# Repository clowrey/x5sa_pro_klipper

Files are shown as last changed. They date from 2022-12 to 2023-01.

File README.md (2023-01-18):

# x5sa_pro_klipper
Edit: the printer.cfg firmware in the "archive" folder is for the original Tronxy board, new one is for the BTT Octopus Pro I am currently using. 
This firmware is only for the V6-191121 motherboard - based on instructions here: https://tronxy.fandom.com/wiki/Installing_Klipper

To install firmware place the "update" folder on an SD card and power on the printer, it should update and the screen will stop working. It now will work with Klipper!

Install Mainsail OS https://docs.mainsail.xyz/setup/ on your raspberry pi or other SBC

Use basic Klipper guide's to help you get familiar with how Klipper works... 

Copy the "printer.cfg" file contents into Mainsail OS klipper config either through the web interface or through SSH, SFTP etc.. 

I am currently using Bambulabs Studio fork Softfever with the Tronxy with good results, you can import the config for that from the folder in this repository.
https://github.com/SoftFever/BambuStudio-SoftFever

Old:
Install super slicer https://github.com/supermerill/SuperSlicer/releases

File - Import - Import Config Bundle - and use the bundle in this repository

Video of my nozzle + linear rail + lower endstop contact bed leveling setup:
https://youtu.be/urmSgkl6vnU

Video of it printing before attaching accelerometer and motion shaper:
https://youtu.be/9MZbLJ6z8Nc

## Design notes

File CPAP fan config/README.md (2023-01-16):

**Klipper config for CPAP directly to BTT Octopus pro or Mellow Super 8 - or really any MB with similar shematic**

It should work on any of the 3 pin headers because they all use the same basic output schematic. 

The stock 3 pin 2.54mm pitch connector that goes from CPAP driver PCB to the variable resistor is actually the same 3 pin connector used on these MB! So you just have to move the pins around with small flat head screwdriver.. 

*Mellow Super 8 section below these pictures*

```yaml
[fan] #        CPAP print Cooling Fan\
pin: PG15 # for ocotopus pro Endstop 7 header
max_power: 1 # adjust below 1 if you would like the max speed to be slower
off_below: 0.2 # minimum speed where the fan starts spinning - on octopus pro this is correct - will be lower maybe 0 on mellow Super 8 because of different GPIO pullup and protection resistors
cycle_time: .0005 # = 2khz - CPAP fan driver recommended range is 2-50khz
```

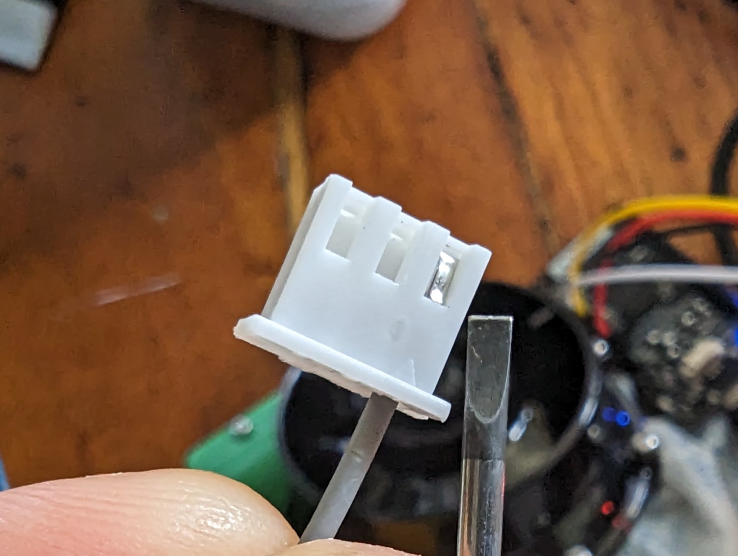
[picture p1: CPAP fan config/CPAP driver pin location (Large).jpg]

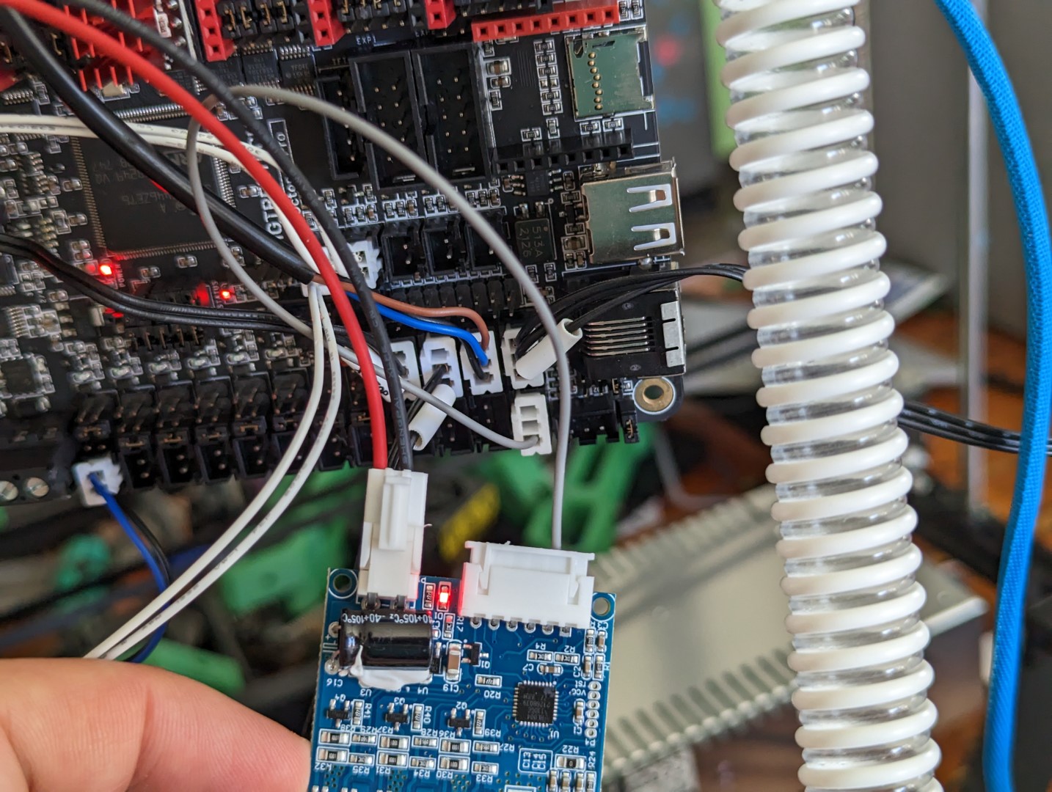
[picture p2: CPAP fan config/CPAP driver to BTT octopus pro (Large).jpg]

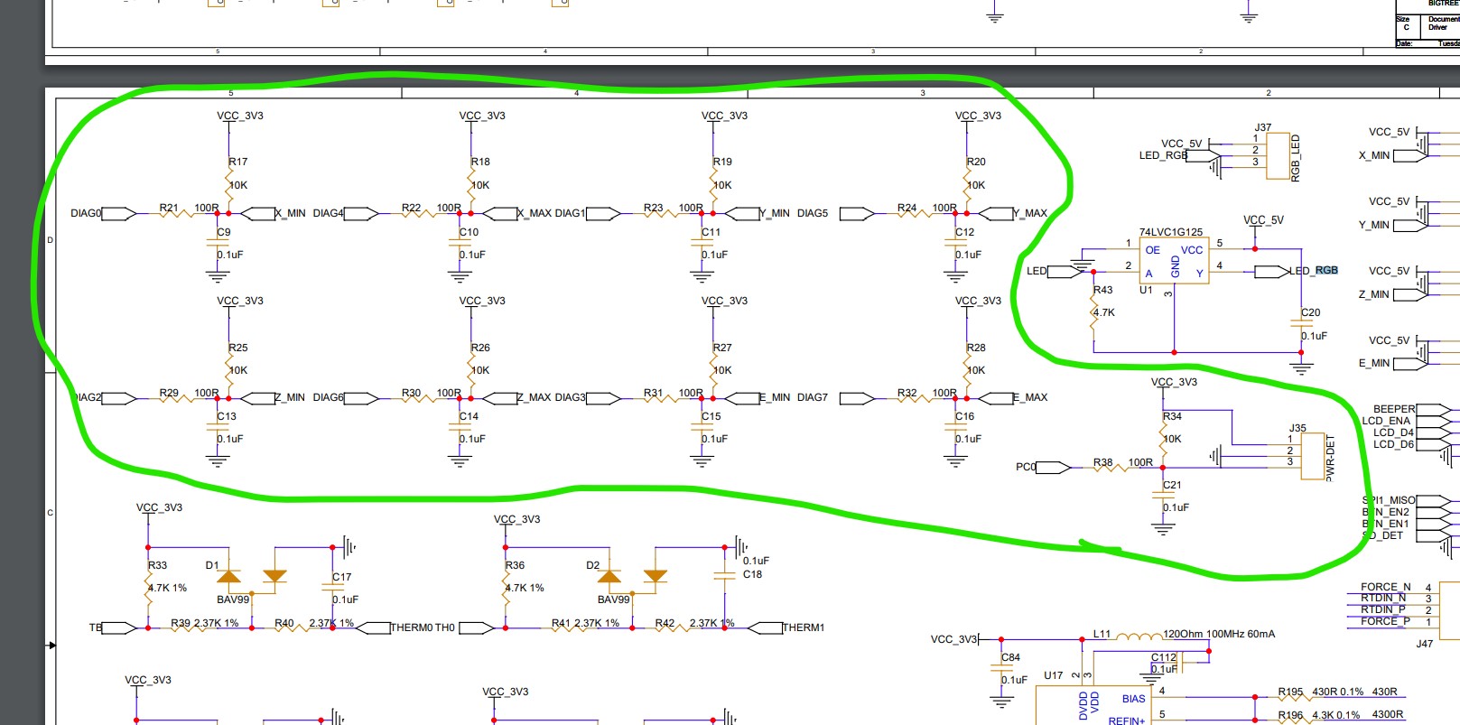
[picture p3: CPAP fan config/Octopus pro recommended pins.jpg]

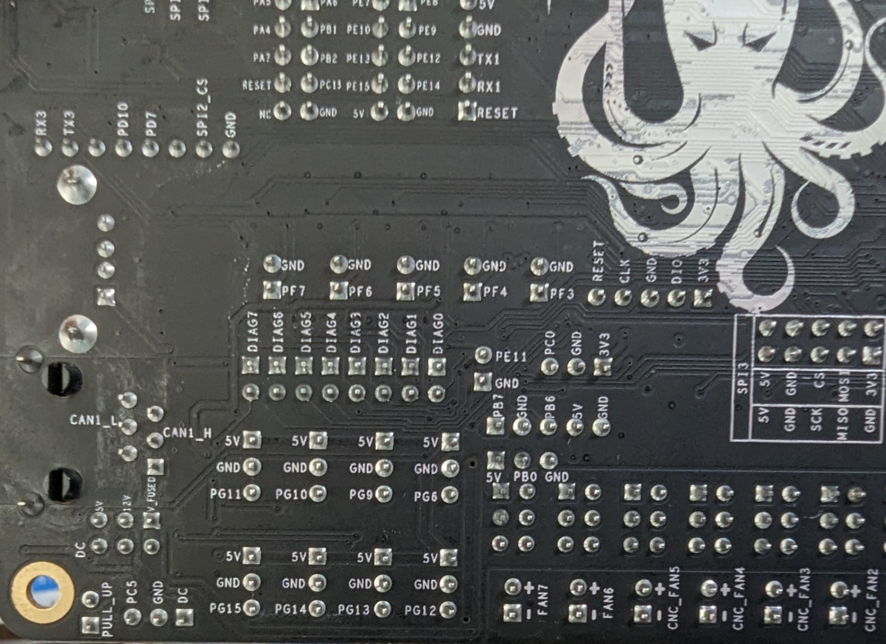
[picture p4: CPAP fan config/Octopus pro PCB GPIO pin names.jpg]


**Mellow Super 8 CPAP Config**

For the Mellow Super 8 the output schematic is quite different - with a 1k series resistor on almost all of the output pins, this in combination with the 10k pullup allows for the lowest voltage to be 0.3v - which is still below the turn on voltage of the CPAP fan driver I believe. 

The green circled HV in pin is the best one to use as it has no pullup. The other ones in yellow have 10k pullups so would be the second choice and should still work fine. 

here is a klipper example using the HV IN header:

```yaml
[fan] #        CPAP print Cooling Fan\
pin: PF3 # for mellow super 8 HI IN header
max_power: 1 # adjust below 1 if you would like the max speed to be slower
off_below: 0.2 # minimum speed where the fan starts spinning - on octopus pro this is correct - 
# will be lower maybe 0 on mellow Super 8 on pins with 10k pullup because of different GPIO pullup and protection resistors
# on HVin pin PF3 it will probably be 0.2 because of no pullup
cycle_time: .0005 # = 2khz - CPAP fan driver recommended range is 2-50khz
```

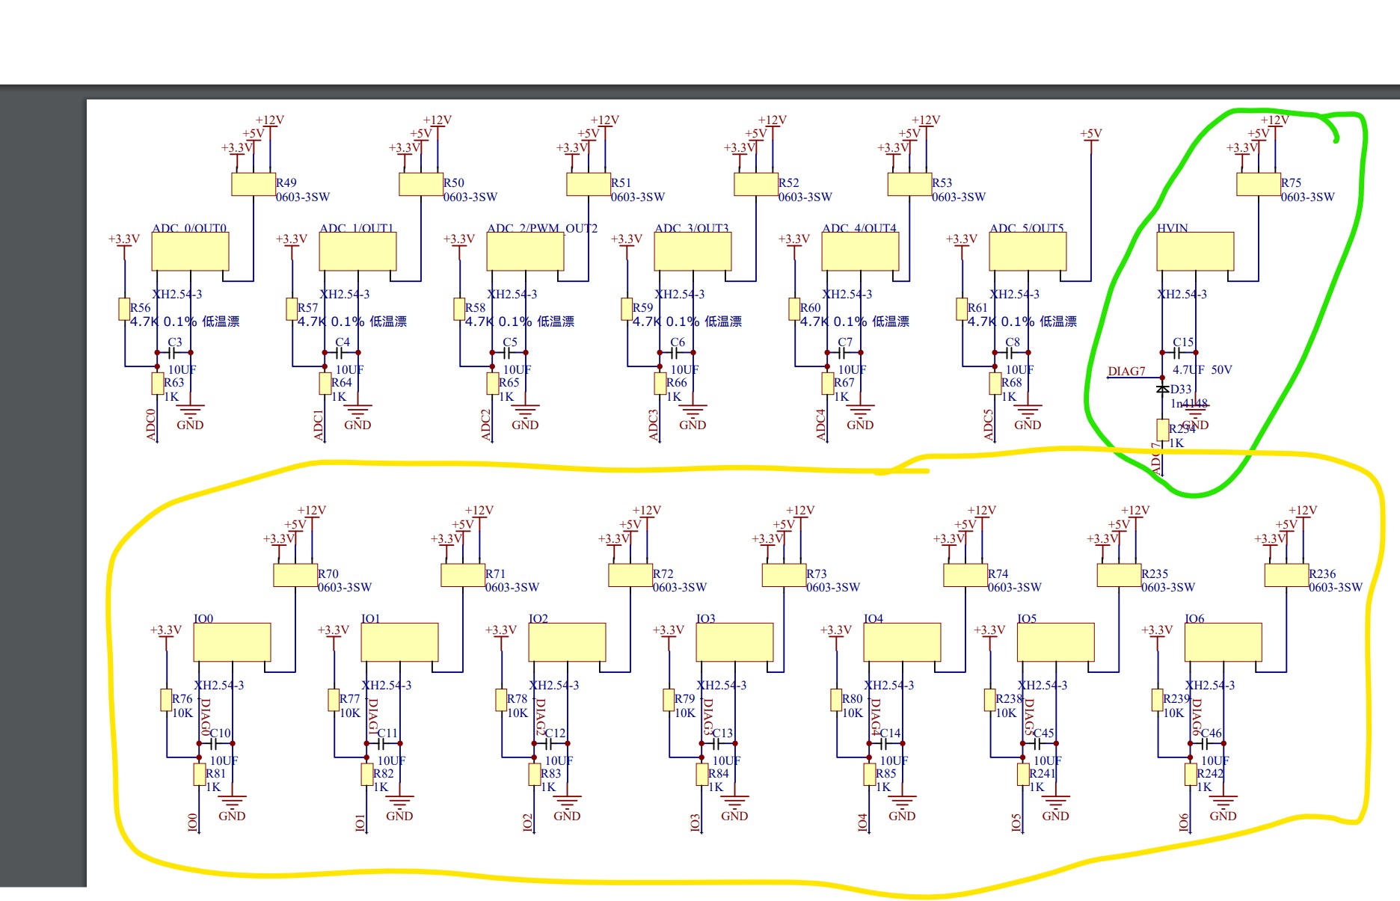
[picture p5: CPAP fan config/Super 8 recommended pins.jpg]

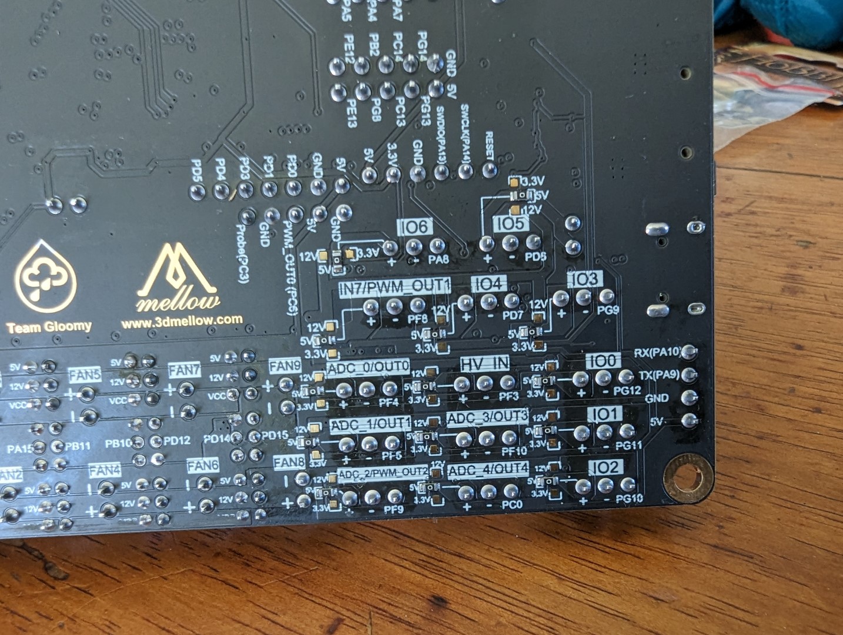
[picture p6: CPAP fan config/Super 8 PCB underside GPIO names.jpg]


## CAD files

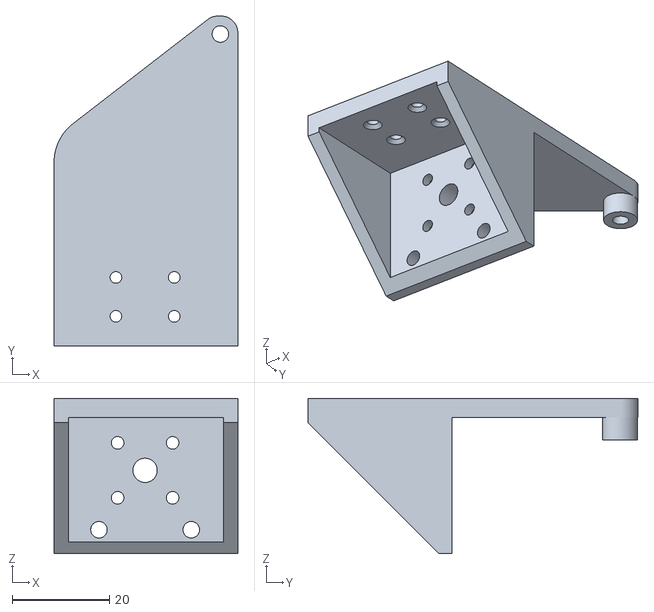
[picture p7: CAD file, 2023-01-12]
tronxy mount linear rail.stl
37.8 x 67.9 x 32.0

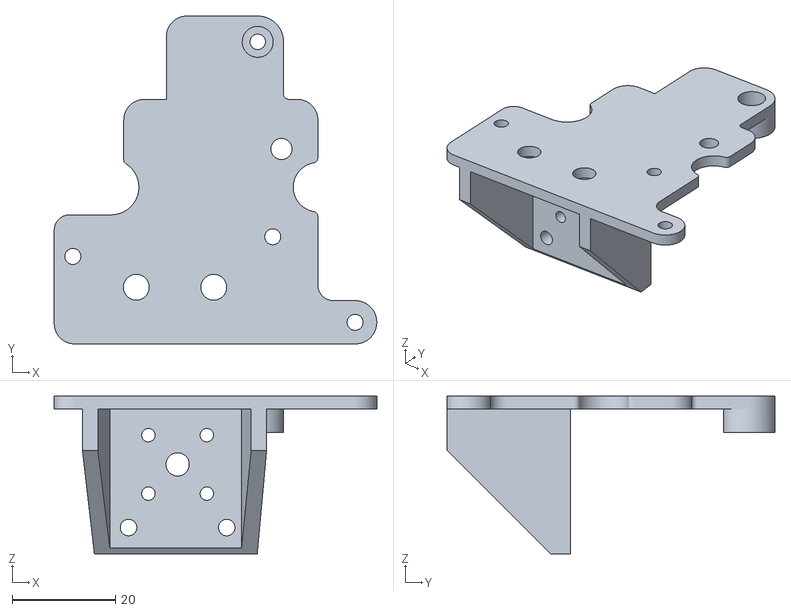
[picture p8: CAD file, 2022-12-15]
extruder_tronxy.obj
62.4 x 63.5 x 30.5

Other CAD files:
tronxy mount linear rail.obj

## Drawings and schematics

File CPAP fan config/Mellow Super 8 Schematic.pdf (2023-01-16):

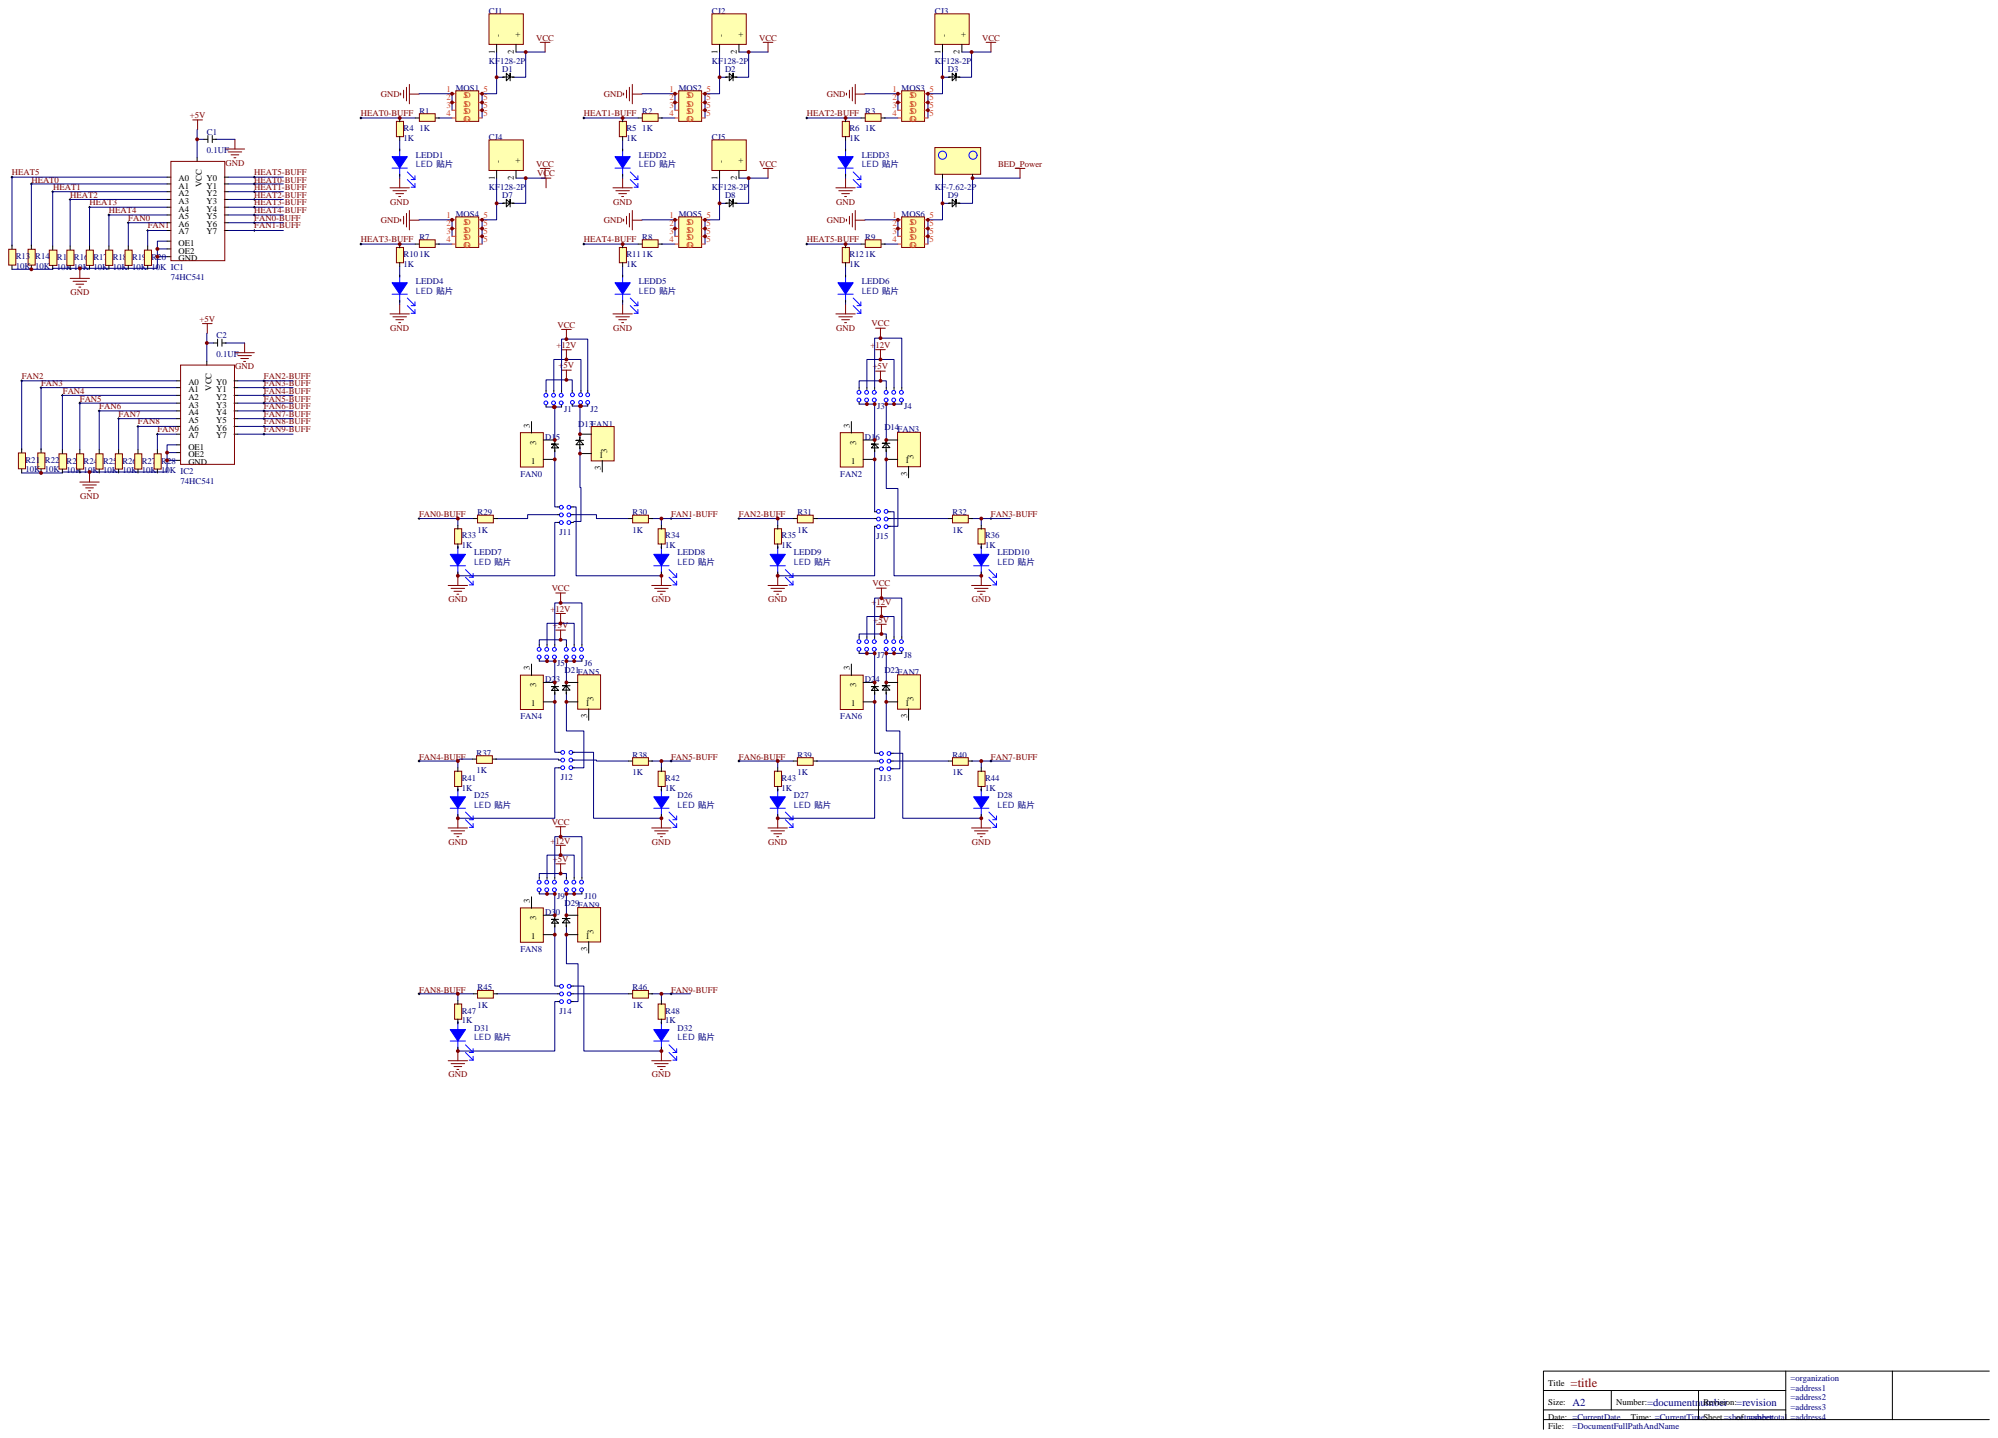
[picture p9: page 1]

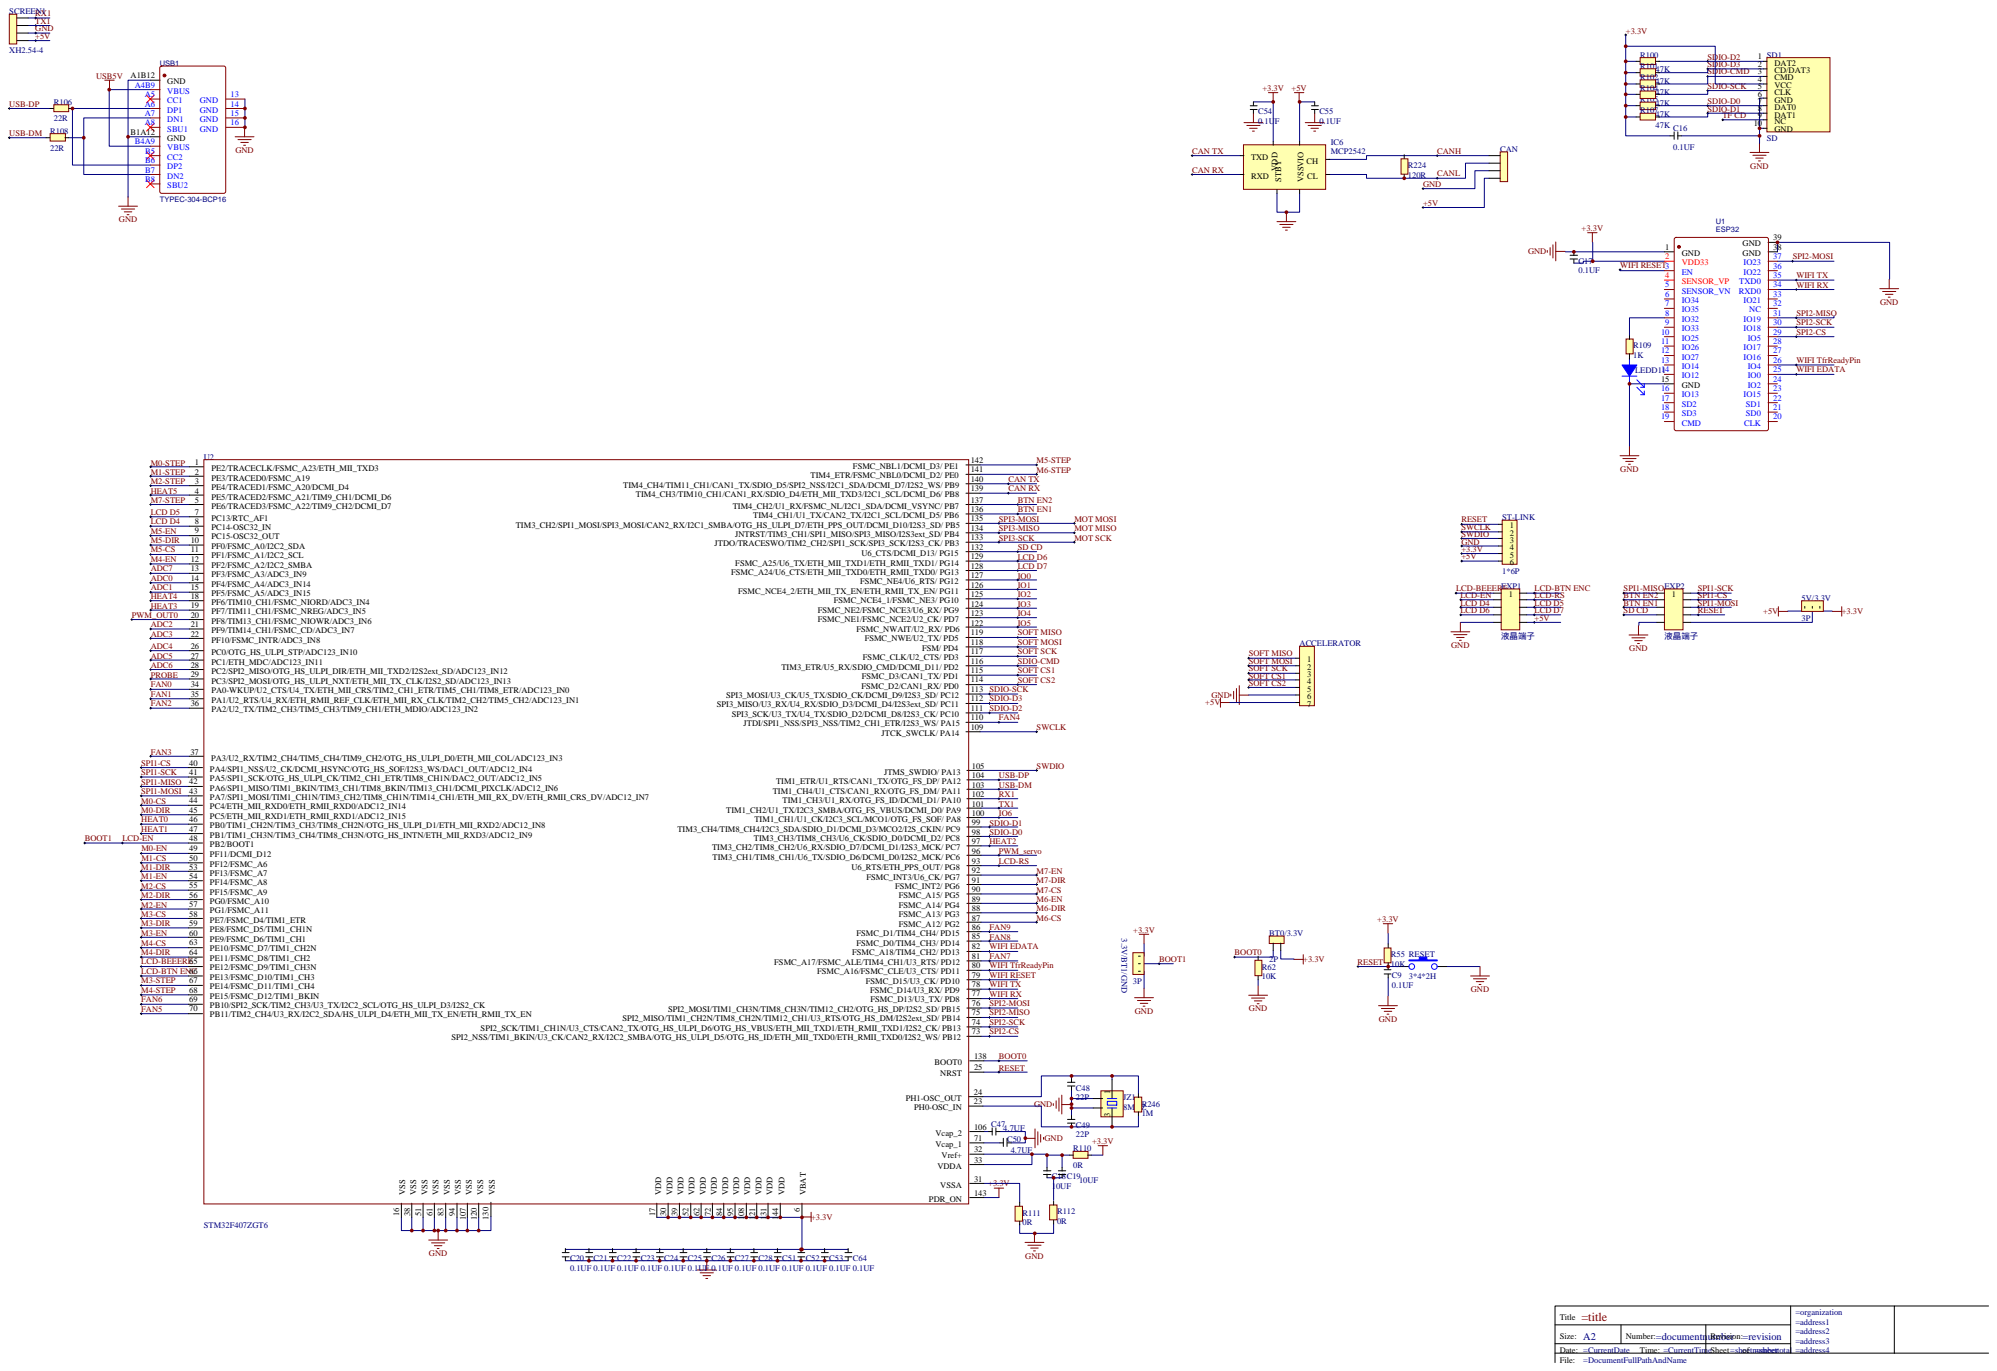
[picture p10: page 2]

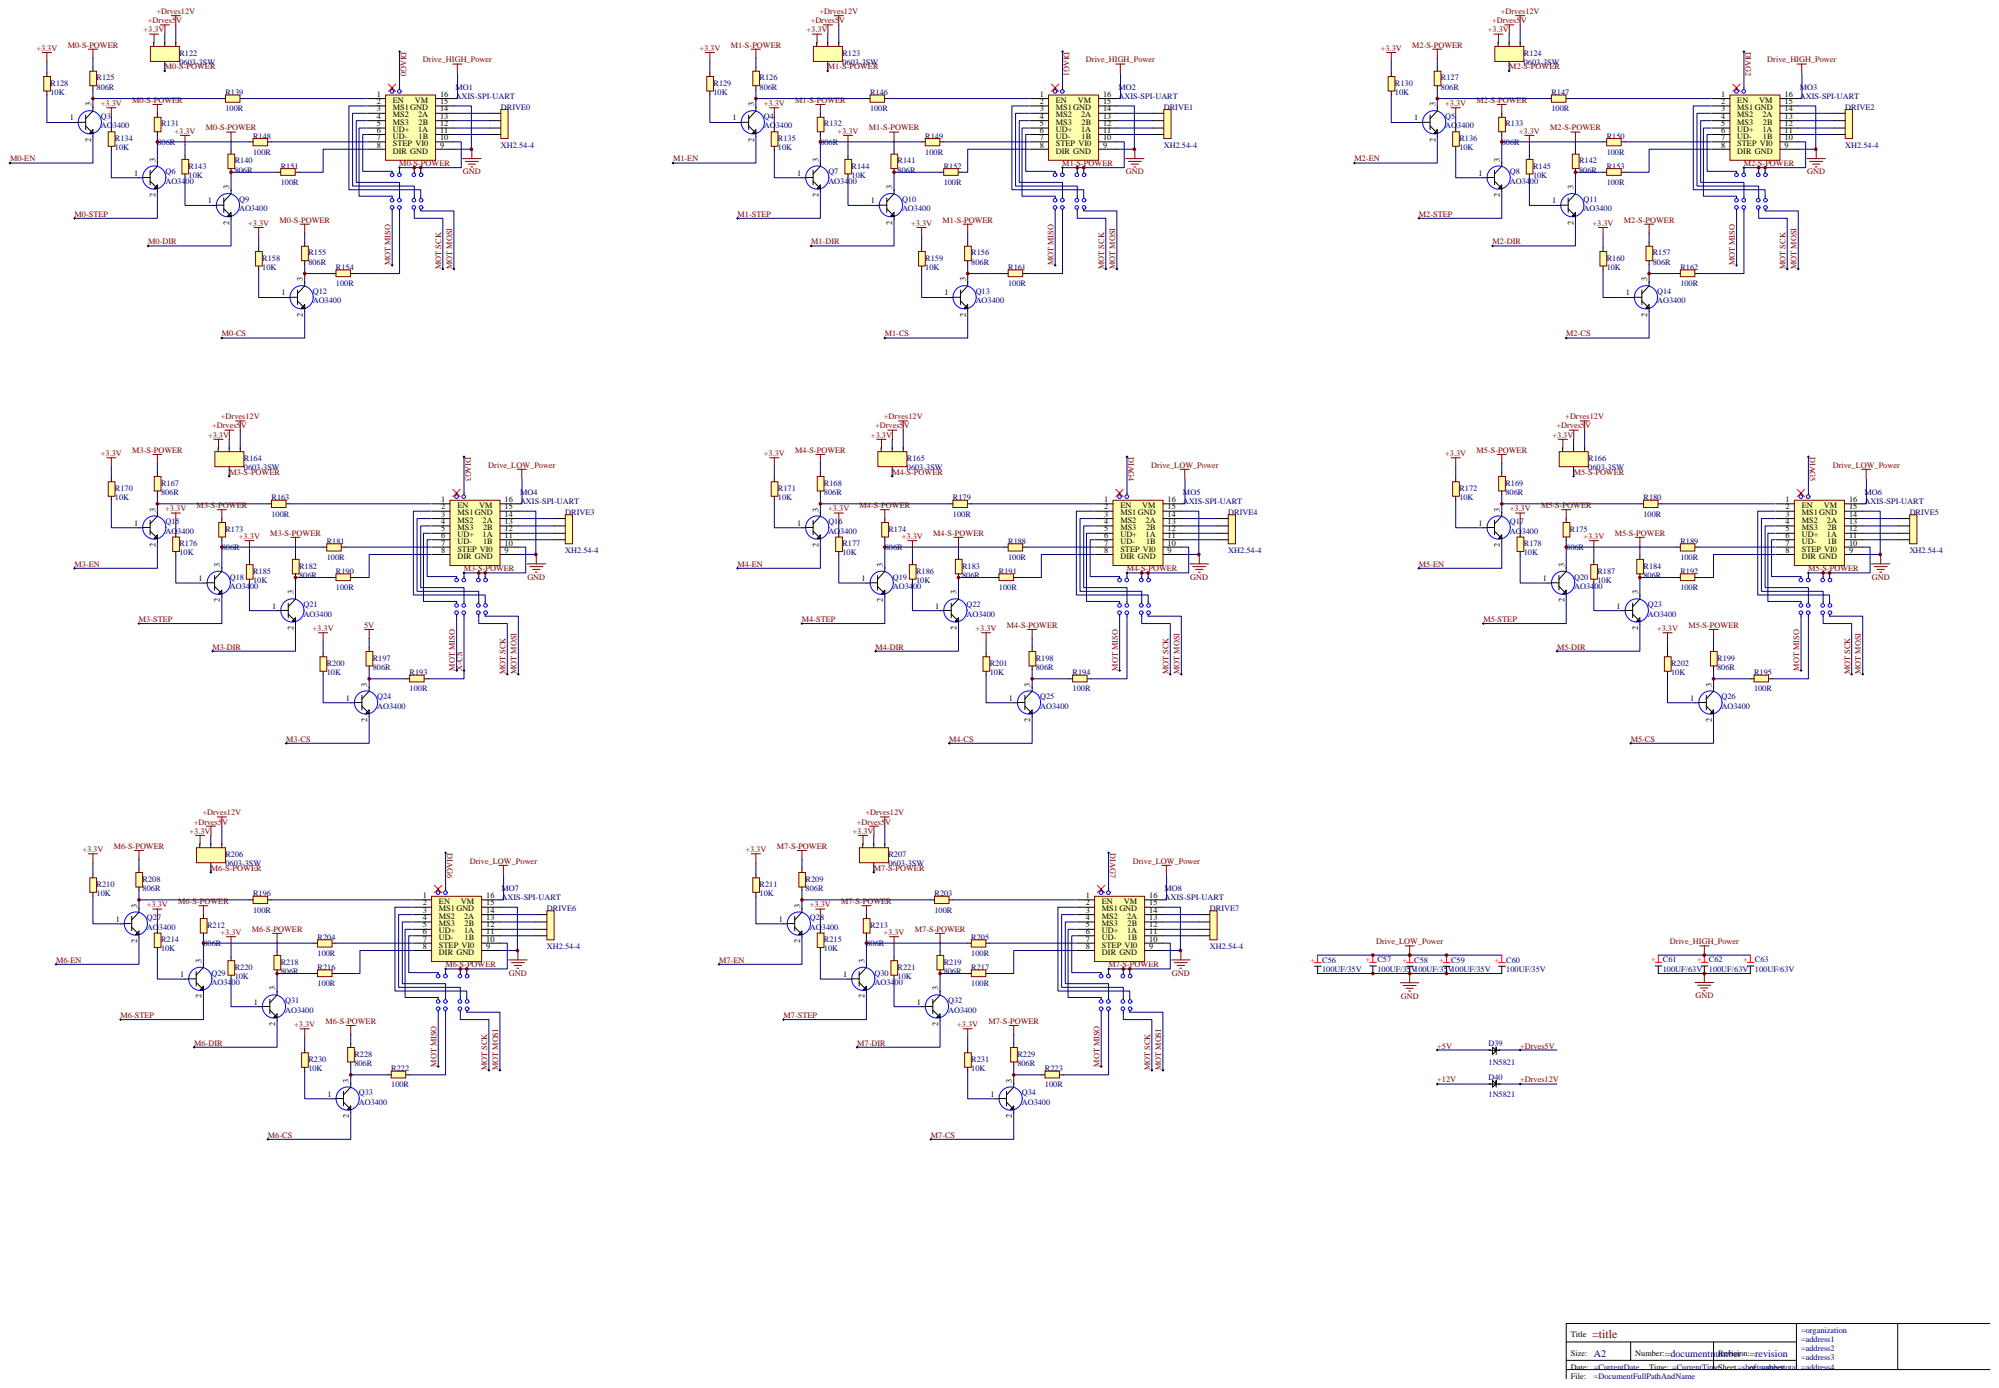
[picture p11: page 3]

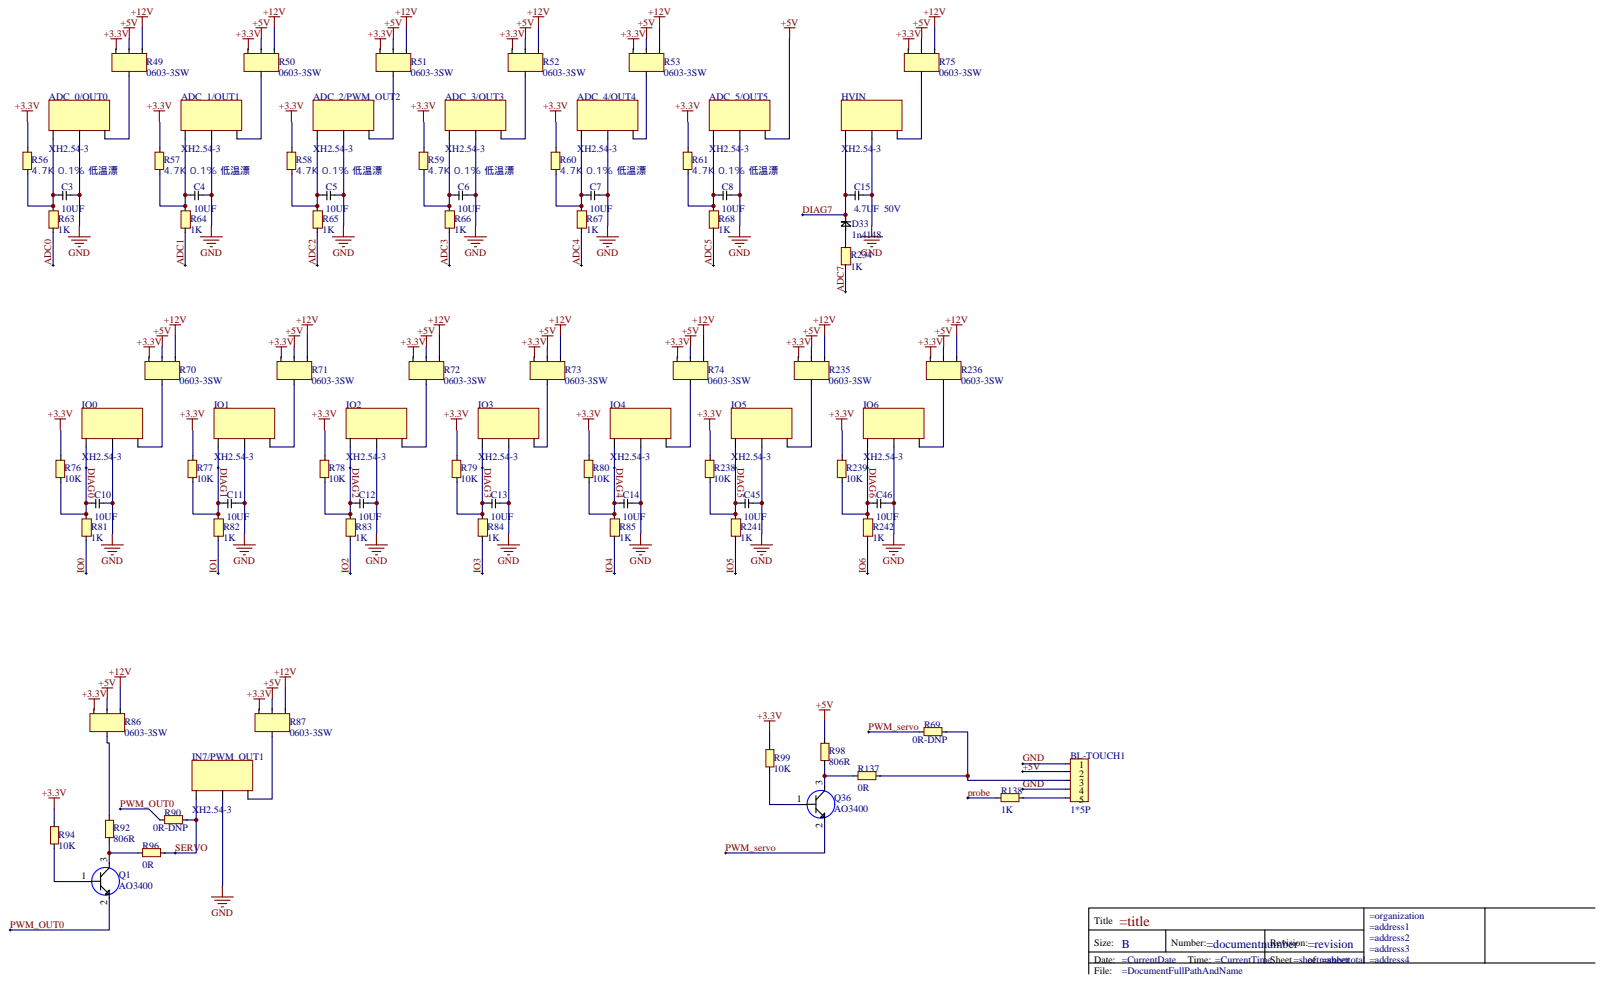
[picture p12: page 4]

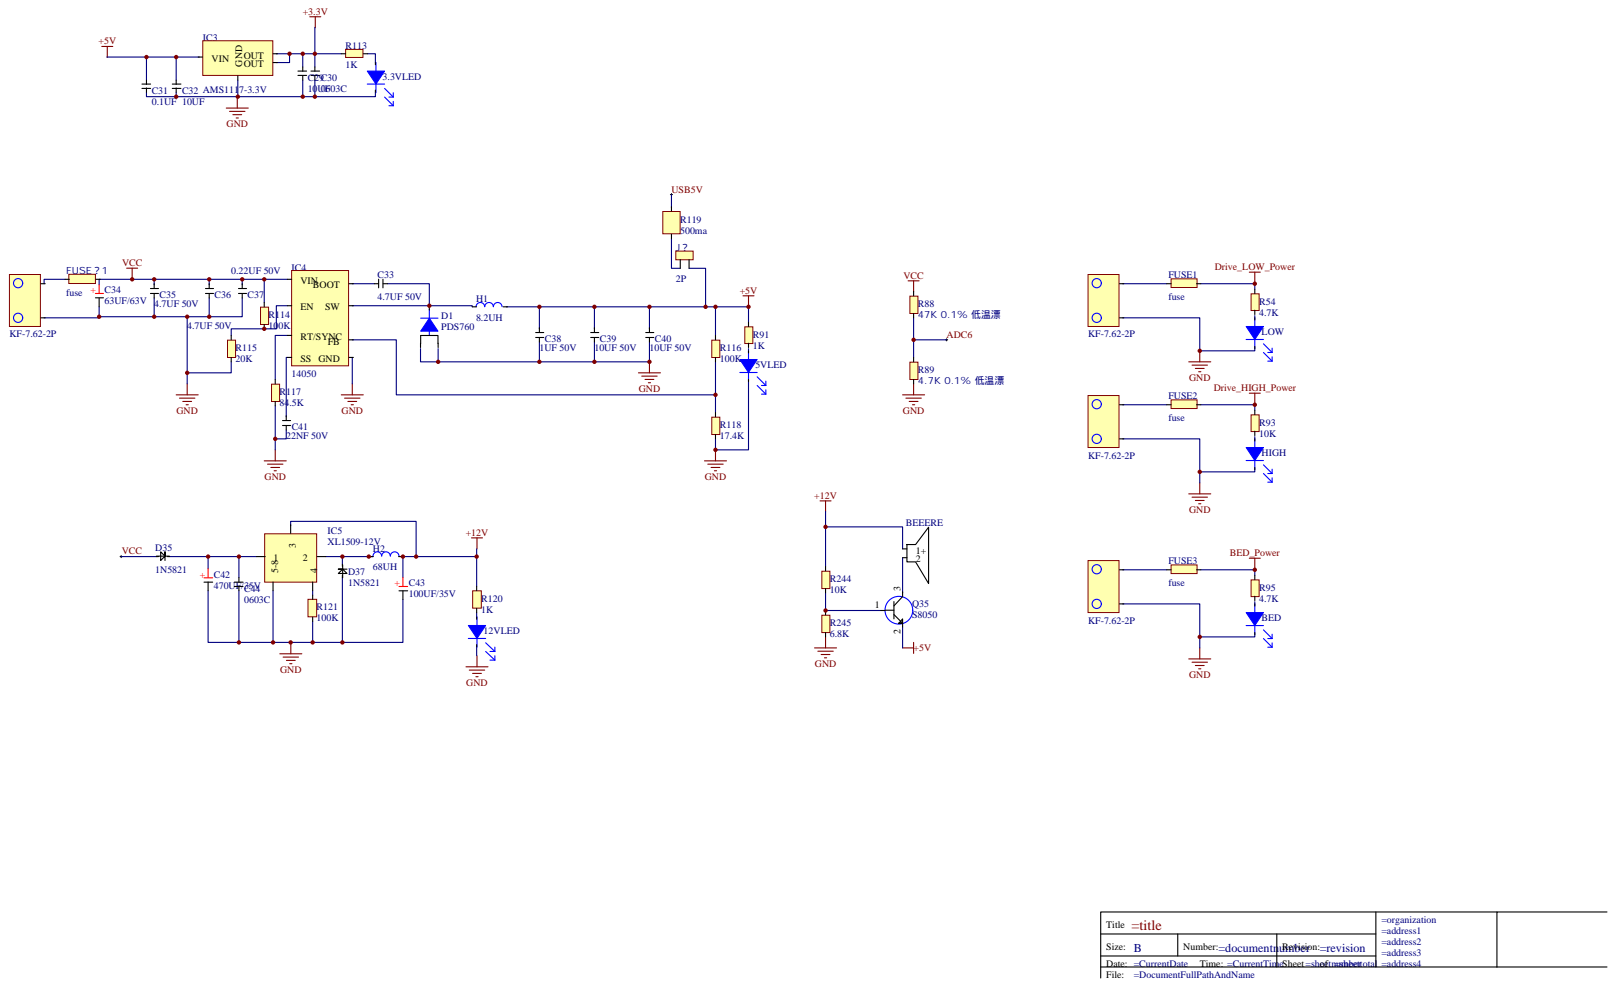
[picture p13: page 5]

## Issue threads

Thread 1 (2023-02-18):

CPAP octopus pro

bsilly1, 2023-02-18:
where did you connect power to? I went off your GitHub page. But when I power on it goes full blast until klipper turns on? I went to the power supply currently.

clowrey, 2023-02-18:
Yes, that is because of how the GPIO pin defaults are set in Klipper firmware - I believe we can fix it by compiling the for ware with a pin over ride turned on for whatever pin you use on the fan. - I haven't tried yet -

When you do the "make menuconfig"  we need a custom setting of "GPIO pins to set at startup"

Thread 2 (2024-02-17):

On Octopus, using Endstop Pin

CD1010, 2024-02-17:
You show for octopus use pG15.  That is an endstop.
Does that really work, because not sure that is PWM able from the docs.

Why not FAN 4 PD14 instead?  ( Or an available PWM FAN PIN )

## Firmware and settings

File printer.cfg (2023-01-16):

# This file contains common pin mappings for the BigTreeTech Octopus
# and Octopus Pro boards. To use this config, start by identifying the
# micro-controller on the board - it may be an STM32F446, STM32F429,
# or an STM32H723.  Select the appropriate micro-controller in "make
# menuconfig" and select "Enable low-level configuration options". For
# STM32F446 boards the firmware should be compiled with a "32KiB
# bootloader" and a "12MHz crystal" clock reference. For STM32F429
# boards use a "32KiB bootloader" and an "8MHz crystal". For STM32H723
# boards use a "128KiB bootloader" and a "25Mhz crystal".

# See docs/Config_Reference.md for a description of parameters.

[include mainsail.cfg]

[pause_resume]

[display_status]

[virtual_sdcard]
path: ~/gcode_files

[mcu]
serial: /dev/serial/by-id/usb-Klipper_stm32f446xx_50005B000451373330333137-if00
# CAN bus is also available on this board

[printer]
kinematics: corexy
max_velocity: 500
max_accel:10000
max_accel_to_decel=2000
square_corner_velocity=5
max_z_velocity: 100
max_z_accel: 50

[gcode_arcs]
#resolution: 1.0

#[mpu9250]
#i2c_mcu: mcu
#i2c_bus: i2c1a

[mcu pico]
serial: /dev/serial/by-id/usb-Klipper_rp2040_DE618CA5873D0C2B-if00

[mpu9250]
i2c_mcu: pico
i2c_bus: i2c1e

[resonance_tester]
accel_chip: mpu9250
probe_points:
    180, 180, 20  # an example

[input_shaper]
shaper_freq_x: 74.6
shaper_type_x: mzv
shaper_freq_y: 38.4
shaper_type_y: mzv



# Driver0
[stepper_x]
step_pin: PF13
dir_pin: !PF12
enable_pin: !PF14
microsteps: 64
full_steps_per_rotation: 200 
rotation_distance: 40
endstop_pin: !PG6
position_endstop: 0
position_max: 350 # for bed mesh
homing_speed: 120
homing_retract_dist: 5
second_homing_speed: 10.0

[tmc5160 stepper_x]
cs_pin: PC4
spi_bus: spi1
##diag1_pin: PG6
sense_resistor: 0.075
interpolate: False
run_current: 1
hold_current: 1
stealthchop_threshold: 0
driver_TBL: 0
driver_TOFF: 1

# Driver1
[stepper_y]
step_pin: PG0
dir_pin: !PG1
enable_pin: !PF15
microsteps: 64
full_steps_per_rotation: 200 
rotation_distance: 40
endstop_pin: !PG9
position_endstop: 0
position_max: 330
homing_retract_dist: 5
homing_speed: 120.0
second_homing_speed: 10.0

[tmc5160 stepper_y]
cs_pin: PD11
spi_bus: spi1
##diag1_pin: PG9
sense_resistor: 0.075
interpolate: False
run_current: 1
hold_current: 1
stealthchop_threshold: 0
driver_TBL: 0
driver_TOFF: 1

# Driver2
[stepper_z]
step_pin: PF11
dir_pin: PG3
enable_pin: !PG5
microsteps: 32
full_steps_per_rotation: 200 
rotation_distance: 8
endstop_pin: probe:z_virtual_endstop
position_max: 400
position_min: -3
homing_retract_dist: 2
homing_speed: 10.0
second_homing_speed: 10.0

[tmc5160 stepper_z]
cs_pin: PC6
spi_bus: spi1
##diag1_pin: PG10
sense_resistor: 0.075
interpolate: False
run_current: 1
hold_current: 0.75
stealthchop_threshold: 0
driver_TBL: 0
driver_TOFF: 1

# Driver4
[extruder]
step_pin: PF9
dir_pin: !PF10
enable_pin: !PG2
microsteps: 32
rotation_distance: 5.6
nozzle_diameter: 0.400
filament_diameter: 1.750
heater_pin: PA2 # HE0
sensor_pin:  PF4 # T0
sensor_type: ATC Semitec 104NT-4-R025H42G
control: pid
pid_Kp: 20.72
pid_Ki: 1.88
pid_Kd: 57.18
min_temp: 0
max_temp: 300
max_extrude_only_distance: 350
pressure_advance: 0.055

[tmc5160 extruder]
cs_pin: PF2
spi_bus: spi1
sense_resistor: 0.075
interpolate: False
run_current: 0.6
hold_current: 0.4
stealthchop_threshold: 0

[filament_switch_sensor sentinel]
pause_on_runout: true
switch_pin: !PG11
runout_gcode:
	G91
    G1 E-30 F2500
  	G90
	G1 X0 Y0 F30000
  	M104 S0

[firmware_retraction]
retract_length: 0.4
retract_speed: 60
unretract_extra_length: 0.00
unretract_speed: 60


[heater_bed]
heater_pin: PA1
sensor_pin: PF3 # TB
sensor_type: ATC Semitec 104GT-2
control: pid
pid_Kp: 66.746
pid_Ki: 3.504
pid_Kd: 317.878
min_temp: 0
max_temp: 130

[idle_timeout]
timeout: 1200

[heater_fan hotend_fan]
heater: extruder
heater_temp: 50.0
pin: PA8

#[heater_fan fan1]
#pin: PE5

#[heater_fan fan2]
#pin: PD12

#[heater_fan fan3]
#pin: PD13

#[heater_fan fan4]
#pin: PD14

#[controller_fan fan5]
#pin: PD15

[safe_z_home]
home_xy_position: 180, 180
speed: 200
#   Speed at which the toolhead is moved to the safe Z home
#   coordinate. The default is 50 mm/s
z_hop: 2
#   Distance (in mm) to lift the Z axis prior to homing. This is
#   applied to any homing command, even if it doesn't home the Z axis.
z_hop_speed: 10
#   Speed (in mm/s) at which the Z axis is lifted prior to homing. The
#   default is 15 mm/s.

[probe]
x_offset: 0
y_offset: 0
z_offset: 0
pin: PG10
speed: 10
#   Speed (in mm/s) of the Z axis when probing. The default is 5mm/s.
samples: 3
#   The number of times to probe each point. The probed z-values will
#   be averaged. The default is to probe 1 time.
sample_retract_dist: 2.0
#   The distance (in mm) to lift the toolhead between each sample (if
#   sampling more than once). The default is 2mm.
#lift_speed:
#   Speed (in mm/s) of the Z axis when lifting the probe between
#   samples. The default is to use the same value as the 'speed'
#   parameter.
#samples_result: average
#   The calculation method when sampling more than once - either
#   "median" or "average". The default is average.
#samples_tolerance: 0.100
#   The maximum Z distance (in mm) that a sample may differ from other
#   samples. If this tolerance is exceeded then either an error is
#   reported or the attempt is restarted (see
#   samples_tolerance_retries). The default is 0.100mm.
#samples_tolerance_retries: 0
#   The number of times to retry if a sample is found that exceeds
#   samples_tolerance. On a retry, all current samples are discarded
#   and the probe attempt is restarted. If a valid set of samples are
#   not obtained in the given number of retries then an error is
#   reported. The default is zero which causes an error to be reported
#   on the first sample that exceeds samples_tolerance.

[bed_mesh]
speed: 120
probe_count: 5, 5
horizontal_move_z: 1
algorithm: lagrange
mesh_min : 30, 30
mesh_max : 300, 300
mesh_pps: 0
;fade_start: 1  #fades out the compensation over a certain distance so Z is eventually not adjusted during horizontal print moves. 
;fade_end: 10
;fade_target: 0

[static_digital_output disable_max31865]
pins: !PF8

[bed_screws]
screw1: 5, 5
screw2: 165, 5
screw3: 325, 5
screw4: 5, 325
screw5: 165, 325
screw6: 325, 325

[board_pins]
aliases:
    # EXP1 header
    EXP1_1=PE8, EXP1_2=PE7,
    EXP1_3=PE9, EXP1_4=PE10,
    EXP1_5=PE12, EXP1_6=PE13,    # Slot in the socket on this side
    EXP1_7=PE14, EXP1_8=PE15,
    EXP1_9=<GND>, EXP1_10=<5V>,

    # EXP2 header
    EXP2_1=PA6, EXP2_2=PA5,
    EXP2_3=PB1, EXP2_4=PA4,
    EXP2_5=PB2, EXP2_6=PA7,      # Slot in the socket on this side
    EXP2_7=PC15, EXP2_8=<RST>,
    EXP2_9=<GND>, EXP2_10=PC5

# See the sample-lcd.cfg file for definitions of common LCD displays.

# A [probe] section can be defined instead with a pin: setting identical
# to the sensor_pin: for a bltouch
#[bltouch]
#sensor_pin: PB7
#control_pin: PB6
#z_offset: 0

#[neopixel my_neopixel]
#pin: PB0

#*# <---------------------- SAVE_CONFIG ---------------------->
#*# DO NOT EDIT THIS BLOCK OR BELOW. The contents are auto-generated.
#*#
#*# [bed_mesh default2]
#*# version = 1
#*# points =
#*# 	0.059167, 0.082500, 0.095833, 0.038333, 0.037500
#*# 	0.013333, 0.065833, -0.008333, 0.015833, 0.019167
#*# 	0.017500, 0.059167, -0.000833, 0.000833, -0.025833
#*# 	0.012500, 0.009167, -0.023333, -0.030833, -0.026667
#*# 	0.051667, 0.048333, 0.015000, -0.006667, -0.007500
#*# x_count = 5
#*# y_count = 5
#*# mesh_x_pps = 0
#*# mesh_y_pps = 0
#*# algo = lagrange
#*# tension = 0.2
#*# min_x = 30.0
#*# max_x = 300.0
#*# min_y = 30.0
#*# max_y = 300.0

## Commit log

2022-12-12 add klipper
    [printer.cfg]
2022-12-16 Create tronxy mount linear rail.obj
    [tronxy mount linear rail.obj]
2023-01-16 update klipper config
    [printer.cfg]
2023-01-16 add cpap fan config
